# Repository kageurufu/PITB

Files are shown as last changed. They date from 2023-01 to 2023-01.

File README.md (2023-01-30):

FYSETC, DFH, and frank.af present  
Party in the Back
=================

[FYSETC Repository here](https://github.com/FYSETC/FYSETC-PITB)

A CAN-enabled 24-60V dual driver printer control board, sized to fit on the rear extrusion of CoreXY printers.

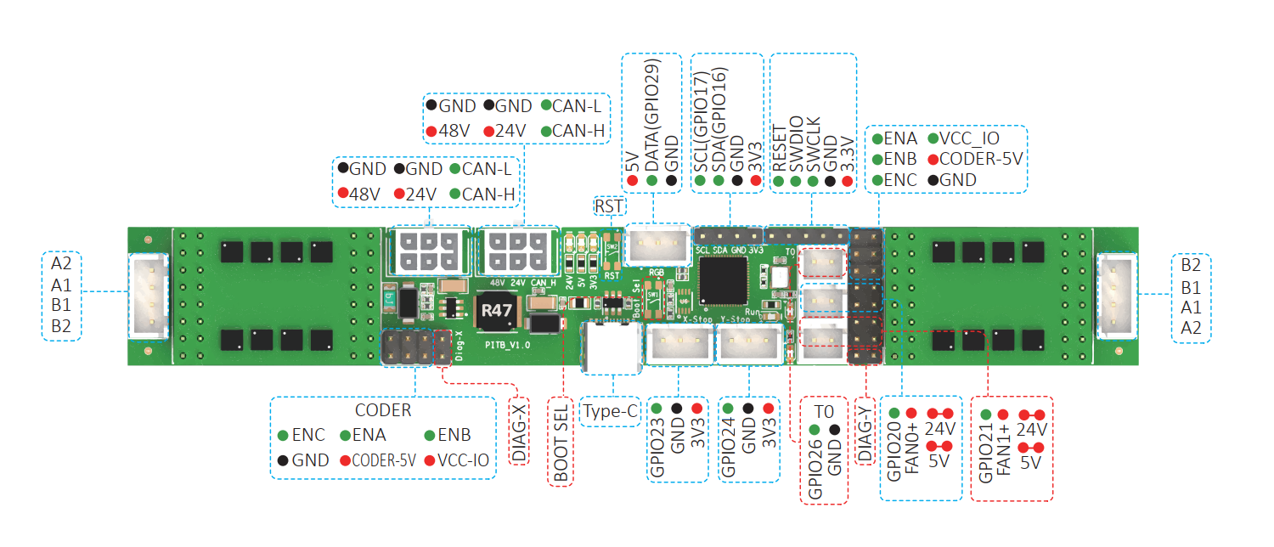
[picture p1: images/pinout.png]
Party in the Back Pinout Pinout


### Features

* Only 150x20mm, with centered mounting holes to fit right on your extrusion
* RP2040 Microprocessor
* TMC5160 Drivers, using FYSETC's BIG5160 modules for up to 60V 6A per stepper
* Two fan control connectors, either 5V or 24V selectable
* Thermistor connector, for reading chamber temperatures
* Two endstop connectors, 3.3V logic level
* Neopixel RGB connectors
* I2C connector for smart peripherals (displays, sensors, and more)

### [Get started with Firmware](./firmware/)

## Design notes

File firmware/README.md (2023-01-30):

CanBoot
=======

I highly recommend flashing [Arksine's CanBoot bootloader](https://github.com/Arksine/CanBoot), to make future firmware updates far easier.

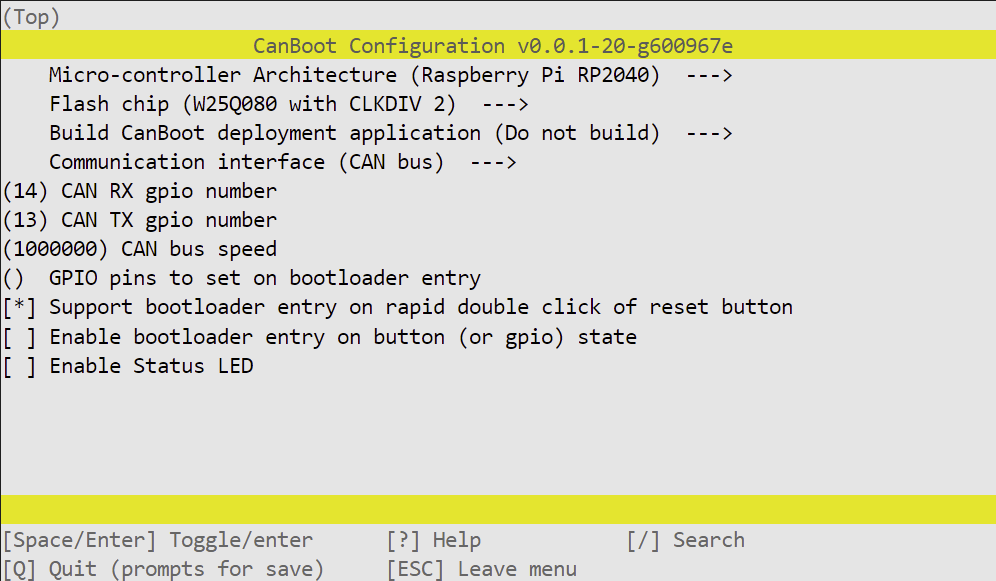
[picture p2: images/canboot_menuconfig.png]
CanBoot menuconfig Canboot menuconfig


Note, you may need to change the CAN bus speed to match your network, although I recommend running above 650,000bps when using two CAN boards.

Connect PITB using a USB-C cable, and press RESET while holding the BOOTSEL button. PITB will present itself to your computer as a USB storage device. Copy the generated `out/canboot.uf2` to PITB and it should reset, and be ready to continue over CAN.

Klipper Configuration
=====================

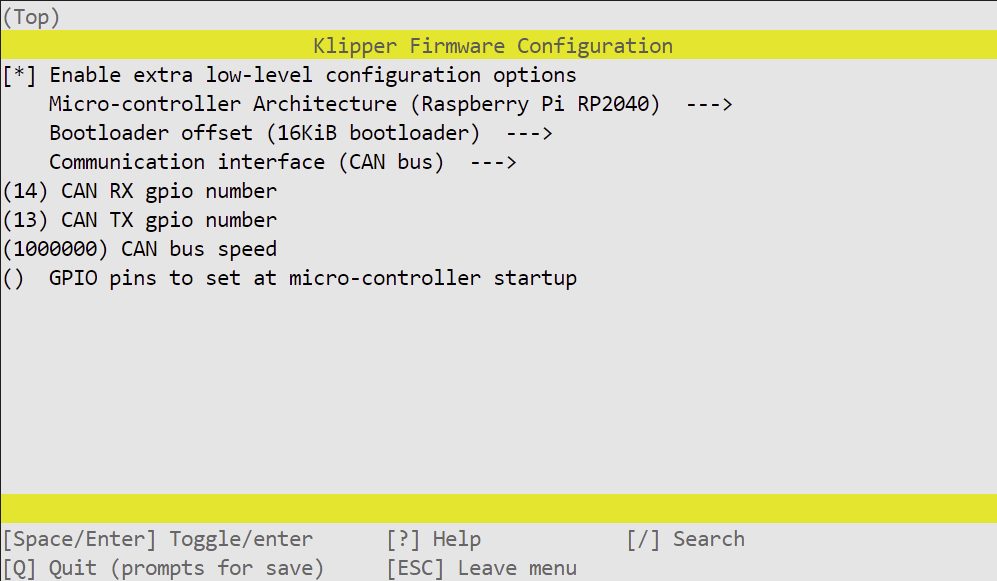
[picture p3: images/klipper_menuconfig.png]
Klipper menuconfig


Again, make sure the CAN bus speed matches your network.

You can identify your PITB's canbus_uuid using `~/klippy-env/bin/python ~/klipper/scripts/canbus_query.py can0`. I used `C0FFEEC0FFEE` here as an example, replace that with your UUID.

Use `~/klippy-env/bin/python ~/klipper/lib/canboot/flash_can.py -u "C0FFEEC0FFEE" -f "~/klipper/out/klipper.bin"` to flash your board

```ini
[mcu pitb]
canbus_uuid: C0FFEEC0FFEE
```

Aliases for board pins, so you can just say `pitb:FAN1` instead of needing to lookup `pitb:gpio21`

```ini 
[board_pins pitb]
mcu: pitb
aliases:
    ## Board enable LED
    LED_RUN=gpio15,

    ## Can pins. STANDBY can be pulled low if you're running USB to disable the transceiver
    ## https://www.nxp.com/docs/en/data-sheet/TJA1040.pdf page 4
    CAN_TX=gpio13, CAN_RX=gpio14, CAN_STANDBY=gpio25,

    ## SPI for motors. spi_bus: spi0a
    MISO=gpio0, MOSI=gpio3, SCLK=gpio2,

    ## Stepper pins
    MOT1_EN=gpio5, MOT1_CS=gpio6,  MOT1_DIR=gpio7,  MOT1_STEP=gpio8,
    MOT2_EN=gpio9, MOT2_CS=gpio10, MOT2_DIR=gpio11, MOT2_STEP=gpio12,

    ## Endstop pins, or DIAG with jumpers
    ENDSTOP_X=gpio23, ENDSTOP_Y=gpio24,

    ## I2C bus: i2c0e
    SCL=gpio17, SDA=gpio16,

    ## Other IO
    FAN0=gpio20, FAN1=gpio21, THERM0=gpio26,
    RGB=gpio29,
```

Stepper pin definitions, you'll need to include your printer's values. You can copy these from existing `[stepper_]` sections

```ini
[stepper_x]
step_pin = pitb:MOT1_STEP
dir_pin = pitb:MOT1_DIR
enable_pin = !pitb:MOT1_EN
endstop_pin = tmc5160_stepper_x:virtual_endstop
## These values are for a Voron 2.4, you need to use the correct values for your printer
# rotation_distance = 40
# microsteps = 16
# full_steps_per_rotation = 200
# position_min = 0
# position_endstop = 305
# position_max = 305
# homing_speed = 20
# homing_positive_dir = true
# homing_retract_dist = 0

[stepper_y]
step_pin = pitb:MOT2_STEP
dir_pin = pitb:MOT2_DIR
enable_pin = !pitb:MOT2_EN
endstop_pin = tmc5160_stepper_y:virtual_endstop
## These values are for a Voron 2.4, you need to use the correct values for your printer
# rotation_distance = 40
# microsteps = 16
# full_steps_per_rotation = 200
# position_min = 0
# position_endstop = 305
# position_max = 305
# homing_speed = 20
# homing_positive_dir = true
# homing_retract_dist = 0
```

PITB uses TMC5160 drivers, comment out or remove any other `[tmcXXXX stepper_x]` or `[tmcXXXX stepper_y]` sections. Configure `run_current` and `hold_current` to meet your needs

```ini
[tmc5160 stepper_x]
spi_bus = spi0a
cs_pin = pitb:MOT1_CS
diag0_pin = ^!pitb:ENDSTOP_X
run_current = 1
hold_current = 1
sense_resistor = 0.075
driver_sgt = 1

[tmc5160 stepper_y]
spi_bus = spi0a
cs_pin = pitb:MOT2_CS
diag0_pin = ^!pitb:ENDSTOP_Y
run_current = 1
hold_current = 1
sense_resistor = 0.075
driver_sgt = 1
```

The RP2040 on PITB has a builtin temperature sensor. This is only useful for seeing if the MCU is getting too hot, it will not give you any idea of chamber temperature

```ini
[temperature_sensor pitb_mcu]
sensor_type = temperature_mcu
sensor_mcu = pitb
```

The Thermistor port on PITB can be used for chamber temperature, the printed mount includes a slot to hold a standard hotend thermistor

```ini    
### Connect a spare thermistor to T0 for accurate chamber readings
[temperature_sensor chamber]
sensor_pin: pitb:THERM0
pullup_resistor: 4700
# sensor_type: ATC Semitec 104GT-2
# sensor_type: PT1000
```

PITB has two fan headers, which you can use to cool board and stepper drivers, your steppers, or anything else you may want to be blowing air for. Both 5V and 24V fans are usable, by moving the FAN0 and FAN1 power jumper

```ini
[fan pitb_fan_0]
pin: pitb:FAN0
max_power: 1.0

[fan pitb_fan_1]
pin: pitb:FAN1
max_power: 1.0
```

PITB has a connector for running Neopixel LEDs, such as the [Adafruit 16 NeoPixel Ring](https://amzn.to/3Cj2fHV)

```ini
[neopixel pitb]
pin: pitb:RGB
chain_count: 16
color_order: GRB
initial_RED: 0.3
initial_GREEN: 0.3
initial_BLUE: 0.3
```

As well, an I2C header is available. This can be used to drive SSD1306 displays, such as this [2.42" 128X64 OLED Module](https://amzn.to/3VhMmYL)

```ini
[display]
lcd_type: ssd1306
i2c_mcu: pitb
i2c_bus: i2c0e
```

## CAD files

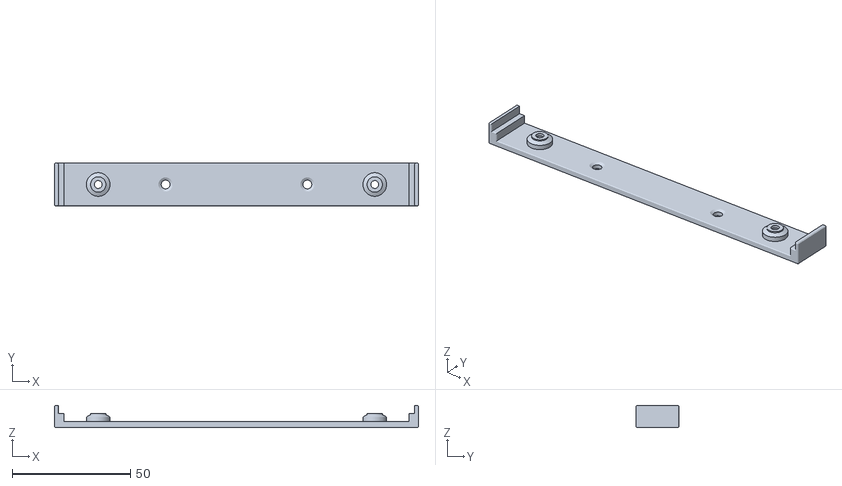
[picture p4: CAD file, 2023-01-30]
STLs/PITB Support.stl
154.0 x 18.0 x 9.40

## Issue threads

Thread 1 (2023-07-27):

Unable to write tmc spi 'stepper_x' register GLOBALSCALER

rbentoski2113, 2023-07-27:
so i got everything else working then as soon as i go to move either of the steppers it shoots this error.   the configs on this repo  and on fystecs repo give the same ill give both klip logs attached, im stumped and im sure its something obvious but if anyone could help would be much appreciated
[klippy (8).log](https://github.com/kageurufu/PITB/files/12179053/klippy.8.log)
[klippy (9).log](https://github.com/kageurufu/PITB/files/12179056/klippy.9.log)

rbentoski2113, 2023-07-29:
Solved,    On these boards the 48v in needs to be powered, even just jumping the 24 over does the trick. i saw a post in passing that the HV 5160 need that circut to power the cs pin i guess,   dont quote me on that but all i know is it worked for me!

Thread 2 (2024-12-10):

Struggling to get PITB UUID over CAN/

LadPack, 2024-12-10:
am trying and failing to have the Party in the back (PITB) board recognized.

I know the CAN wiring is correct, because I have it daisy chained with a toolhead board (downstream of the PITB) that is running fine on klipper, it's just the PITB board that isn't running

I'm using these settings https://github.com/kageurufu/PITB/tree/main/firmware
I am able to see the board over USB, but once I put it into the CAN network I see just the toolhead board like below.

I have also double triple checked the wiring on the board and made sure it is getting the appropriate power.

I am following esotericals guide online, including all of the steps for troubleshooting no UUID, I have reinstalled the katapult software multiple times, each time it appears to install normally.

FWIW, I did have to take down the CAN network and then bring it back up with 1m and qlen 1024, and that worked for the toolhead board (ebb36) that I was able to successfully install klipper on.

I have also removed the ebb36 from the loop, and am now just trying to flash the PITB on it's own.  I have also tried with and without the CAN FD Jumper

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

LadPack, 2024-12-10:
Closing issue, the make menuconfig here is for v1,a nd I have a v2.
